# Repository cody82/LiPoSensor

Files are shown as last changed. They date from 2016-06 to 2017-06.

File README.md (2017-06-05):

# LiPoSensor
This is a Li-Poly voltage sensor that connects to Frsky receivers or to flight controllers that
support one of the Frsky telemetry protocols.
This repository includes the Arduino source code and the KiCad PCB.

# Compiling
You need Arduino >= 1.6.

# Board
*WARNING: DO NOT POWER THE BOARD FROM BOTH LIPO AND RECEIVER AS IT MIGHT CATCH FIRE*

You need KiCad >= 4.0 to edit the PCB.

You can order the PCB from OSH Park:



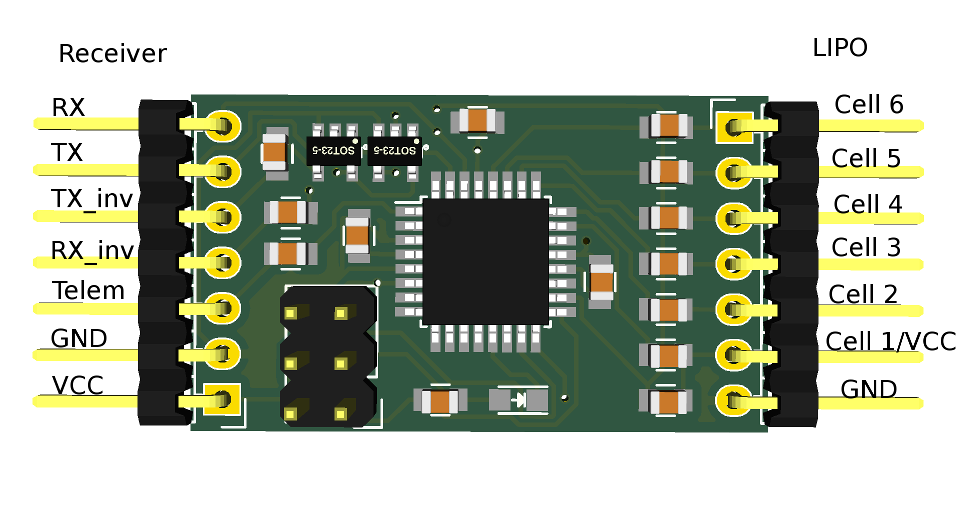
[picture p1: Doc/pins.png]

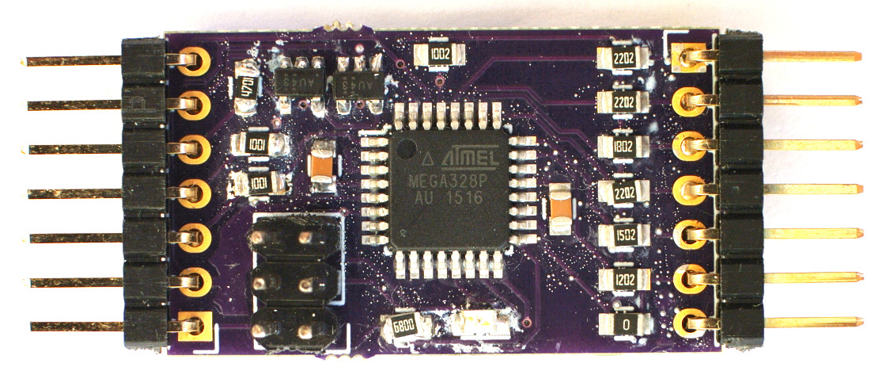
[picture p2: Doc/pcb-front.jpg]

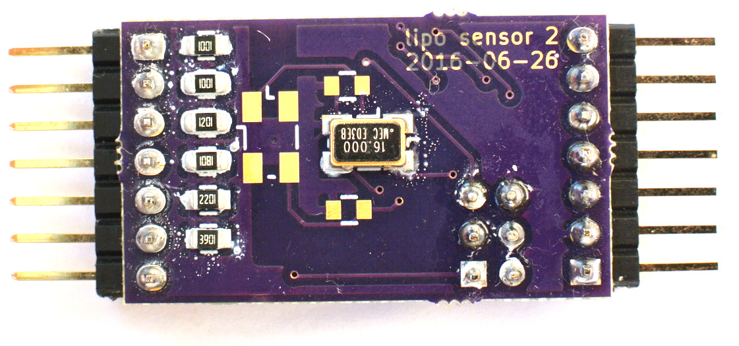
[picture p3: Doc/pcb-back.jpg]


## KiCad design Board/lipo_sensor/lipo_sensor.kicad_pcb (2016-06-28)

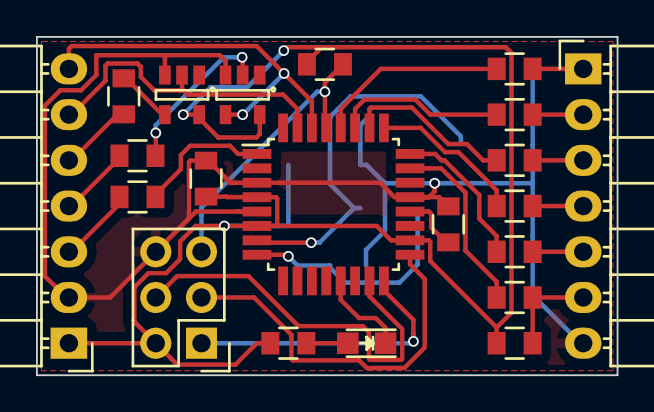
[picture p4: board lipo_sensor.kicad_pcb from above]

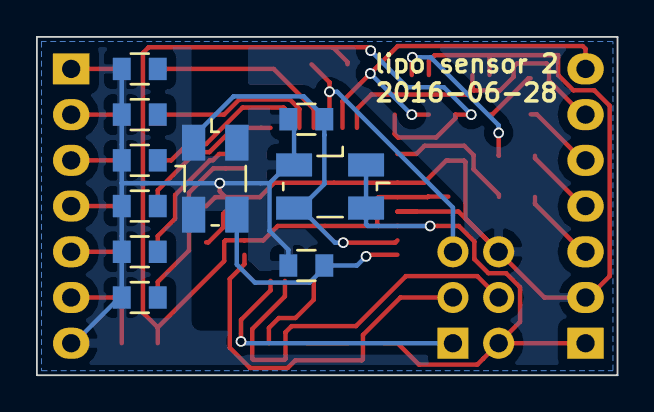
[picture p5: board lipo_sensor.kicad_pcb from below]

Board: 2 copper layers, 32.3 x 18.8 mm, 31 parts (10 on the bottom side), 31 nets.

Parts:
5k1: 4k7; C_0805
C1, C3: 100nF; C_0805
C2, C5: 22pF; C_0805
D1: LED; LED_0805
IC1: ATMEGA328P-A; TQFP-32_7x7mm_Pitch0.8mm
P1: CONN_02X03; Pin_Header_Straight_2x03
P2, P3: CONN_01X07; Pin_Header_Angled_1x07
P4: OSZILLATOR; Oszillator_SMD_5032_4Pads
P5, P6: INVERTER; SOT-23-5
P7: QUARZ; Oszillator_SMD_5032_4Pads
R1: 680; C_0805
R2, R5, R9: 22k; C_0805
R3, R6: 1k; C_0805
R4: 0; C_0805
R7: 18k; C_0805
R8: 1k2; C_0805
R10: 1k8; C_0805
R11: 15k; C_0805
R12: 2k2; C_0805
R13: 12k; C_0805
R14: 3k9; C_0805
R15, R17: R; C_0805
R16: 10k; C_0805

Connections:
/Cell1: IC1.23, R13.2, R14.1
/Cell2: IC1.24, R11.2, R12.1
/Cell3: IC1.25, R9.2, R10.1
/Cell4: IC1.26, R7.2, R8.1
/Cell5: IC1.27, R5.2, R6.1
/Cell6: IC1.28, R2.2, R3.1
/LED: D1.1, IC1.13
/RX: IC1.30, P2.7, P6.4
/S.Port: 5k1.2, IC1.1
/TX: IC1.31, P2.6, P5.2
GND: C1.2, C2.1, C3.1, C5.1, IC1.3, IC1.5, IC1.21, P1.6, P2.2, P3.7, P4.2, P5.3, P6.3, R3.2, R6.2, R8.2, R10.2, R12.2, R14.2
unnamed: 5k1.1, P2.3
unnamed: C2.2, IC1.7, P4.3, P7.1
unnamed: C3.2, IC1.20
unnamed: C5.2, IC1.8, P7.3
unnamed: D1.2, R1.2
unnamed: IC1.15, P1.4
unnamed: IC1.16, P1.1
unnamed: IC1.17, P1.3
unnamed: IC1.29, P1.5, R16.2
unnamed: P2.4, R17.2
unnamed: P2.5, R15.2
unnamed: P3.1, R2.1
unnamed: P3.2, R5.1
unnamed: P3.3, R7.1
unnamed: P3.4, R9.1
unnamed: P3.5, R11.1
unnamed: P3.6, R4.2, R13.1
unnamed: P5.4, R15.1
unnamed: P6.2, R17.1
VCC: C1.1, IC1.4, IC1.6, IC1.18, P1.2, P2.1, P4.1, P4.4, P5.5, P6.5, R1.1, R4.1, R16.1

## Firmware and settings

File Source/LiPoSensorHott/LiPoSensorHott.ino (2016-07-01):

#include <SoftwareSerial.h>

#define HOTTRX 3
#define HOTTTX 3
SoftwareSerial hottSerial(HOTTRX, HOTTTX);
static volatile boolean inAscii = false;
static float VoltageAlarm = 9.9;
float Voltage = 0;

void setup()
{
  pinMode(9, OUTPUT);
  Serial.begin(9600);
  analogReference(INTERNAL);
}

float voltage(int adc, float r1, float r2)
{
  return (float)adc / 1023.0 * 1.1 * ((r2+r1)/r1);
}

void loop()
{
  int cell1 = analogRead(A0);
  int cell2 = analogRead(A1);
  int cell3 = analogRead(A2);
  int cell4 = analogRead(A3);
  int cell5 = analogRead(A4);
  int cell6 = analogRead(A5);

  float v1 = voltage(cell1, 3.9, 12);
  float v2 = voltage(cell2, 2.2, 15);
  float v3 = voltage(cell3, 1.8, 22);
  float v4 = voltage(cell4, 1.2, 18);
  float v5 = voltage(cell5, 1, 22);
  float v6 = voltage(cell6, 1, 22);

  float w1 = v1;
  float w2 = max(v2 - v1, 0);
  float w3 = max(v3 - v2, 0);
  float w4 = max(v4 - v3, 0);
  float w5 = max(v5 - v4, 0);
  float w6 = max(v6 - v5, 0);
  
  float vfas = w1 + w2 + w3 + w4 + w5 +w6;
  
  Serial.print(vfas);
  Serial.print(";");
  Serial.print(w1);
  Serial.print(";");
  Serial.print(w2);
  Serial.print(";");
  Serial.print(w3);
  Serial.print(";");
  Serial.print(w4);
  Serial.print(";");
  Serial.print(w5);
  Serial.print(";");
  Serial.println(w6);

  Voltage = vfas;
  
  loopHott();
  
  digitalWrite(9, HIGH);
  digitalWrite(9, LOW);
}

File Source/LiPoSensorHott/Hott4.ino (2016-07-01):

#include "HottMessages.h"


#define HottStart 0;
#define AsciiPacket 1
#define BinaryPacket 2;
static int state = 0;

static char sendBuffer[180];

void loopHott() {
  if (hottSerial.available() > 1) {
    
    for(int i = 0; i < 2; i++) {
      uint8_t c = hottSerial.read();
      c = (uint8_t)(c & 0xFF); // nur das lowest byte
      
      switch (state) {
       case 0: // Check first byte
         if(c == 0x7F) { 
           state = AsciiPacket;
           inAscii = true;
         }
         else if(c == 0x80) { 
           state = BinaryPacket; 
           inAscii = false;
         }
         break;
       case 1 : // Ascii
         if((c & 0xF0) == 0xE0) { // Ascii EAM, compare just highest byte
           hottBuildAscii(c);
         }
         state = HottStart;
         // ...
         break;
       case 2 : // Binary
         if(c == 0x8E) { // BinaryEAM;
           hottBuildEAM();
         }
         state = HottStart;
         // ... weitere
         break;
       default:
         state = HottStart;
      }
    }
  }
  
}

void clearLine(int line) {
  memset(&hottASCII.text[line*21], ' ', 21);
}

void clearAll() {
  memset(&hottASCII.text[0], ' ', 21*8);
}

/*
 * Prepares text for sending it to the HoTT display
 * returns the position of the last char printed
 */
int hottPrint(int line, int col, char* text, boolean inv=false) {
  int i = 0;
  while(text[i] != '\0' && i < 21 - col) {
   hottASCII.text[(line * 21) + col + i] = inv ? text[i] | 0x80 : text[i];
   i++;
  }
  return i + col;
}

int curserPos = 1;
boolean voltageAlarmEdit = false;
float voltageAlarmBackupValue = 0;

void hottBuildAscii(byte button) {
  uint8_t key = (uint8_t)(button & 0x0F); // get pressed button
  int voltageposition = 0;
  
  hottASCII.startByte = 0x7B; // 0x7B
  hottASCII.escape = 0xE0; // 0xE0 D=GAM, E=EAM, A=GPS, 9=Vario
  hottASCII.alarm = 0;
  
  // Textmenü generieren
  clearAll();
  
  hottASCII.endByte = 0x7D; // 0x7D
  
  
  hottPrint(0, 0, "Custom HOTTv7");
  
  hottPrint(1, 1, "EAM Emu");
  hottPrint(2, 1, "Reset Vario");
  hottPrint(3, 1, "Reset Capacity");
  
  voltageposition = hottPrint(4, 1, "Lipo Alarm bei: ");
  
  switch(key) {
   case  0x07: 
     // ESC
     if(voltageAlarmEdit) {
       voltageAlarmEdit = false;
       VoltageAlarm = voltageAlarmBackupValue;
     }
     hottASCII.escape = 0x01;
     break;
   case  0x0D: 
     // INC
     if(voltageAlarmEdit) {
       VoltageAlarm += 0.1;
     }
     else if(curserPos < 8) curserPos++;
     break;
   case  0x0B: 
     // DEC
     if(voltageAlarmEdit) {
       VoltageAlarm -= 0.1;
     }
     else if(curserPos > 1) curserPos--;
     break;
   case  0x0E: 
     // ENTER
     break;
   case  0x09: 
     // SET
     if(voltageAlarmEdit) {
       voltageAlarmEdit = false;
       break;
     }
     if(curserPos = 4) {
       voltageAlarmEdit = true;
       voltageAlarmBackupValue = VoltageAlarm;
     }
     break;
   case  0x0F:
   default:
     // NONE
     break;
  }
  
  hottPrint(curserPos, 0, ">");
  
  // print Voltage alarm level
  char buffer[4];
  dtostrf(VoltageAlarm, 1, 1, buffer);
  hottPrint(4, voltageposition, buffer, voltageAlarmEdit);
  
  memcpy(&sendBuffer, &hottASCII, hottAsciiLength);
  
  delay(5);
  if(hottSerial.available() > 0) return; // Data on the line... return
  
  sendHottPacket(hottAsciiLength);
}

void hottBuildEAM() {
  hottEAM.startByte = 0x7C; // 0x7C
  hottEAM.packetId = 0x8E; // 0x8E
  hottEAM.beeps = 0;
  hottEAM.idTextMode = 0xE0; // 0xE0
  hottEAM.inverse = 0;
  hottEAM.inverseStatus = 0;
  
  // Packet befüllen
  hottEAM.cell1L = 210;
  hottEAM.cell2L = 110;
  
  hottEAM.powerV = Voltage;
  hottEAM.current = 0;
  hottEAM.mAh = 0;
  
  hottEAM.temp1 = 0;//(byte)Temperature + 20; // byte!! 46 = 25C, 20 = 0C
  
  hottEAM.altitude = 0;//500 + ((AbsoluteAltitude - GroundAltitude));
  
  hottEAM.climbrate1 = 0;//30000 + (Climbrate1*100);
  hottEAM.climbrate3 = 0;//120;
  
  hottEAM.endByte = 0x7D; // 0x7D
  
  // memcpy ( void * destination, const void * source, size_t num );
  memcpy(&sendBuffer, &hottEAM, hottEAMLength);
  
  delay(5);
  if(hottSerial.available() > 0) return; // Data on the line... return
  
  sendHottPacket(hottEAMLength);
}

void sendHottPacket(int length) {
  pinMode(HOTTRX, OUTPUT); // switchoff RX-Line
  
  int ck = 0;
  for(int i = 0; i < length - 1; i++) {
   ck += sendBuffer[i];
   hottSerial.write(sendBuffer[i]);
  }
  hottSerial.write((byte)ck); // write Checksum
  
  delayMicroseconds(2000); // 2ms
  pinMode(HOTTRX, INPUT);
}

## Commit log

2016-06-17 Arduino wants it like that.
2016-06-18 Add sketch for FrskyD telemetry. https://github.com/jcheger/arduino-frskyd
2016-06-18 Add KiCad board.
    [lipo_sensor-B.Cu.gbl, lipo_sensor-B.Mask.gbs, lipo_sensor-B.SilkS.gbo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]
2016-06-26 Shrink layout and fix oszillator connections.
    [lipo_sensor.kicad_pcb, lipo_sensor.sch]
2016-06-28 Fix inverted RX/TX.
    [lipo_sensor.kicad_pcb, lipo_sensor.sch]
2016-06-28 Replace big crystal with smaller crystal: QC5A Series 3.2x5.0 4-Pad SMD Quartz Crystal Unit
    [lipo_sensor.kicad_pcb]
2016-06-28 Ready for order.
    [lipo_sensor-B.Cu.gbr, lipo_sensor-B.Mask.gbr, lipo_sensor-B.SilkS.gbr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]
2016-06-28 Forgot to commit.
    [lipo_sensor.kicad_pcb]
2016-07-19 Add datasheet.
    [lipo_sensor.sch]
2017-06-05 Add https://github.com/jcheger/arduino-frskyd library as submodule.
